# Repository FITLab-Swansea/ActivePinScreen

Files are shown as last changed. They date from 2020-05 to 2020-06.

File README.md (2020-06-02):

# Active PinScreen
Active PinScreen is a new tactile feedback technique, that applies localised stimuli on multiple fingers with fine spatial and temporal resolution. It uses an array of solenoid-actuated magnetic pins with millimetre scale form-factor which could be deployed for back-of-device handheld use without instrumenting the user.

See the [toolkit website](https://breaking-the-glass.com/toolkit.html) and [research project website](https://breaking-the-glass.com) for more details and related work.
## Getting Start
To build your own Active PinScreen, the following instructions will get you a copy of the project up and running on your local machine for development and testing purposes. See deployment for notes on how to deploy the project on a live Active PinScreen.

As well as presenting a detailed description of the prototype, we provide the potential design configurations and the applications of Active PinScreen.

* [Prototype](Prototype/)
* [Circuit layouts & microcontroller code](Electronics%20and%20microcontroller%20code/)
* Examples of Android App source code see: [TacCar](EndlessRunner), [TacPacMan](TacPacMan) and [TacPinao](TapPinao).

## License

This project is licensed under the MIT License - see the [LICENSE](LICENSE) file for details.

The Active PinScreen's prototype designs, circuit layouts, microcontroller code and accompanying Android app source code are all released.

## Acknowledgments

* FitLab
* Swansea University
* ...

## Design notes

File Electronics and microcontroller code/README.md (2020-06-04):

# Active PinScreen Electronics and Microcontroller
Active PinScreen is controlled using a custom-made circuit board, which runs a 8X8 pin array and a Bluetooth module, and provides handles battery charging.

## Getting Start
This repository provides [circuit diagrams](Gerber%20files/), a [bill of materials](Coil%20array%20BOM.xls) and [parts coordinates list](partslist_coil.xls), a [list of commands](Coils-protocol.pdf), and [general hardware documentation](pintoy_paper.pdf).

You will also need the following (or similar), in addition to the circuit board:

* A Bluetooth HC-05 module
* Two lithium-polymer battery
* Optional: Two DPST switchers ([examples](https://onecall.farnell.com/c-k-components/l201011ss03q/slide-switch-dpst-4a-125v-panel/dp/2931771))
* Optional: Two extra 100 kOhm resistors for the battery monitor feature

The prototype’s solenoids are in practice activated one-by-one, their fast response time, combined with pulse-width modulation means that this is imperceptible to the user. Users are able to feel multiple pins simultaneously.

Therefore, the Active PinScreen, can be programed to form a particular pattern based on the "frame" and "sequence" defined in [Coils array communication protocol](Coils-protocol.pdf).
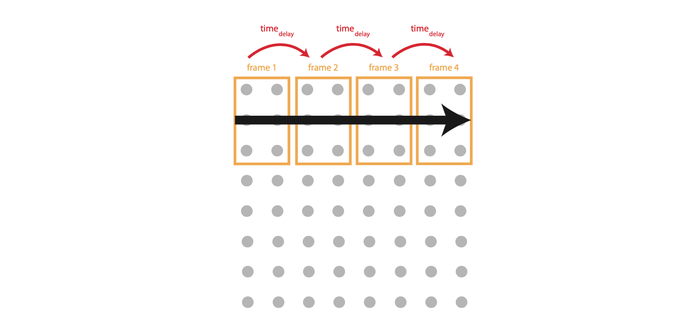
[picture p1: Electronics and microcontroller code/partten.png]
An example of the sequence of left to right directional pattern is shown in the following figure. The stimulation consists of four frames (each consisting of 2 × 3 (W × L) pins). 

## Pattern Programming
In order to create different types of stimuli, we needed to generate a sequence of activated pins in the following way:
* Define a block pattern which is known as a frame. Each pin in a frame will be activated simultaneously (or seemingly so from the user’s perspective, but actually by careful design of the pulse widths and duty cycles of each pin as described below);
* Define the actuation time of each frame, known as time actuation, which is the time each frame continues to be active for;
* Define the frame to frame delay, known as time delay, which refers to the pause between each frame being actuated;
* Create directional pattern by ‘drawing’ each frame on pin array;
* Using the frame and parameters time actuation and time delay, run the stimuli in sequence (i.e., frame by frame)
until the pattern is complete.

## License

This project is licensed under the MIT License - see the [LICENSE](LICENSE) file for details.

The Active PinScreen's prototype designs are released.

## Acknowledgments

* FitLab
* Swansea University
* ...

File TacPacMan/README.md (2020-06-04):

# TacPacMan
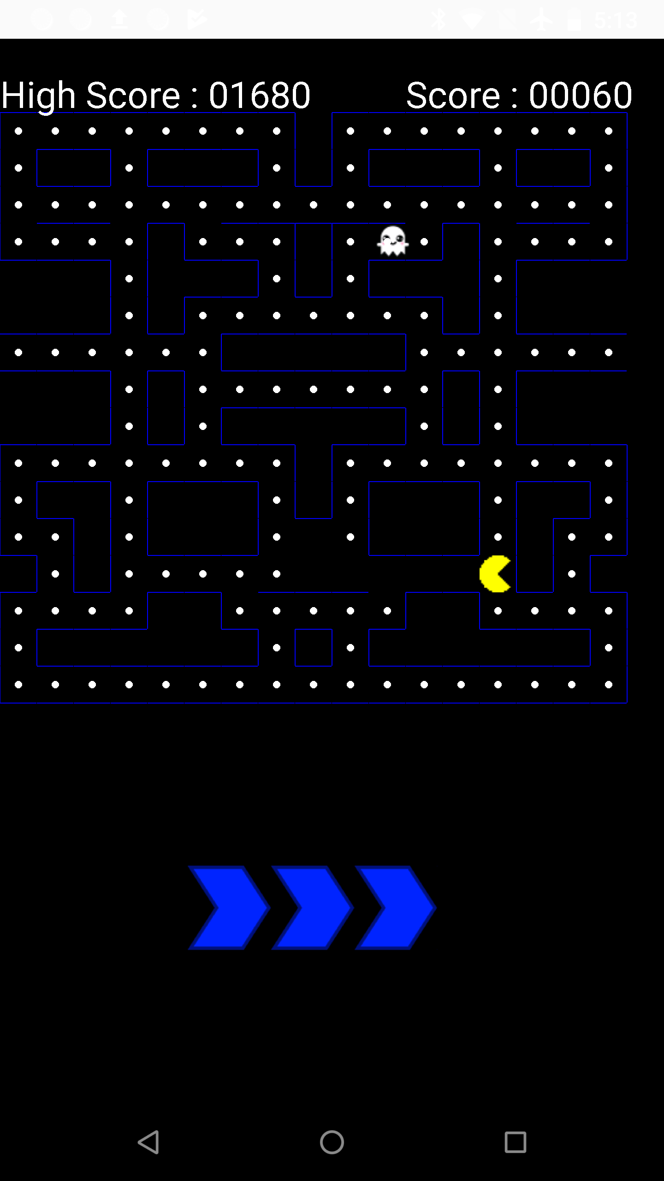
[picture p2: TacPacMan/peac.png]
f1
TacPacMan is an Android game which work with Active PinScreen. The left/right and up/down swipes on the front screen of the Pacman game are reflected within and inter-finger stimuli at the back of the device.

## License

This project is licensed under the MIT License - see the [LICENSE](LICENSE) file for details.

The Active PinScreen's prototype designs, circuit layouts, microcontroller code and accompanying Android app source code are all released.

## Acknowledgments

* FitLab
* Swansea University
* ...

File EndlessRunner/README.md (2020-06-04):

# Endless Runner
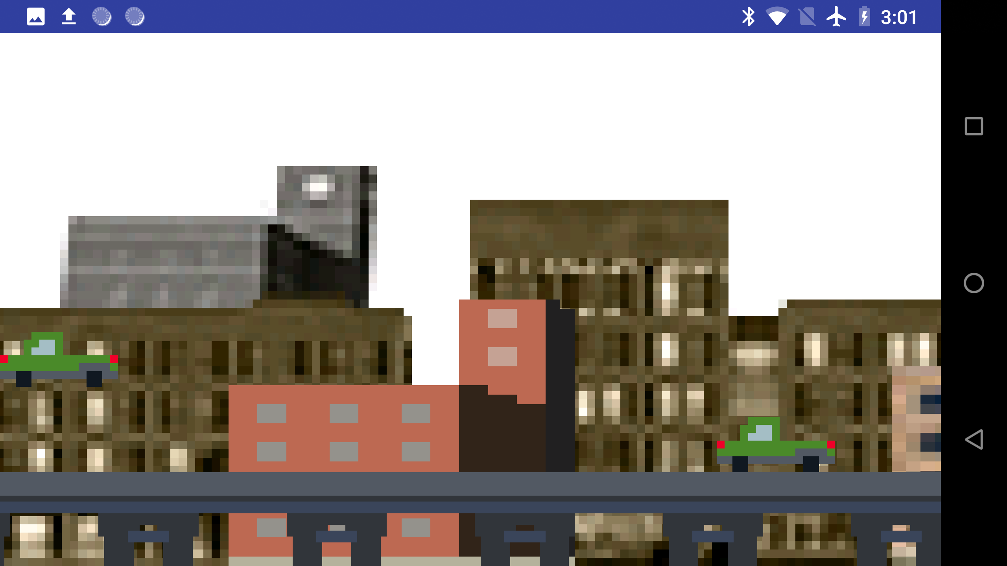
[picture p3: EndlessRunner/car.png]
f1
Endless Runner is an Android game which work with Active PinScreen. The "[car](car.png)" of the game can jump to avoid crush on "[the other car](car.png)" by tapping on the front screen. The inter-finger stimuli at the back of the device mimic this jump action.

## License

This project is licensed under the MIT License - see the [LICENSE](LICENSE) file for details.

The Active PinScreen's prototype designs, circuit layouts, microcontroller code and accompanying Android app source code are all released.

## Acknowledgments

* FitLab
* Swansea University
* ...

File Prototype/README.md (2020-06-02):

# Active PinScreen Prototype
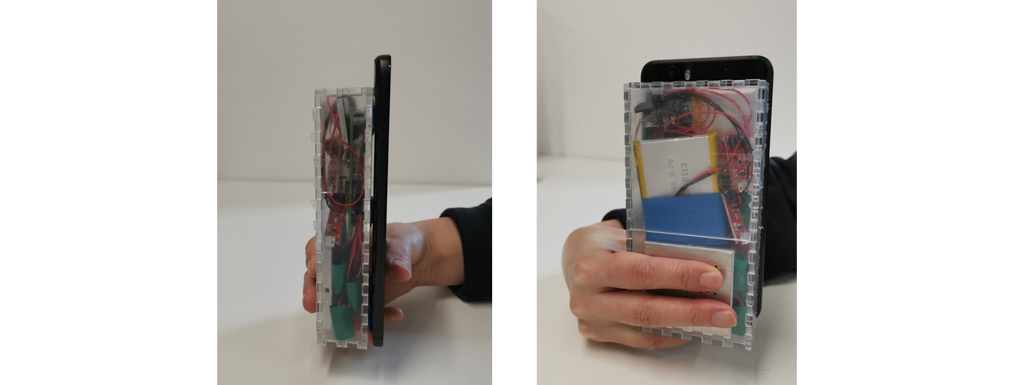
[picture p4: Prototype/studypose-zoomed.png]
The prototype can feasibly fit within the casing of a standard smart-phone -- see the following figure.

## Getting Start
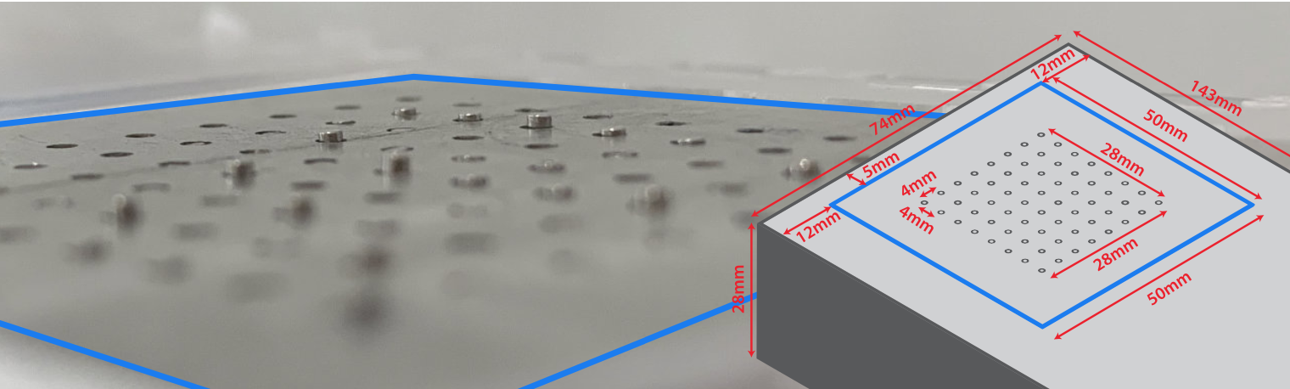
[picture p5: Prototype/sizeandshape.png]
array
The area which provided the tactile feedback are an 8×8 array of pins on the prototype are uniformly distributed over an area of 28 × 28 mm. The blue highlighted area affords the ability to fit comfortably on the back of a standard touchscreen device to provide high-precision feedback to multiple fingers at once. 

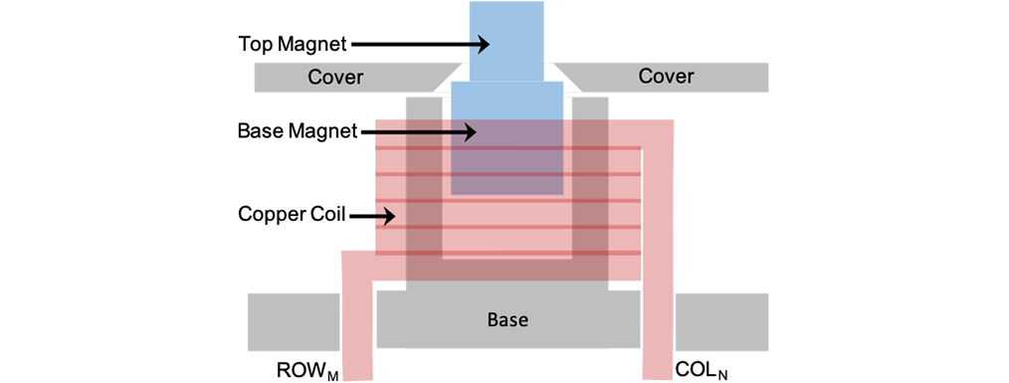
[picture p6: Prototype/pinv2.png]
arra
A close-up view of the device’s 1 mm diameter pins. A schematic of an individual in unit with its linear solenoid actuator and plunger is shown in the following figure.

* The plungers—the moving pins of the Active PinScreen—are magnetic, and consist of two permanent neodymium magnets.
* The base magnets have a diameter and thickness of 1.5 mm, and slide through the air-core of the solenoid, trapped inside by unit’s top-cover. The top magnets are adhered to the base magnets, and have a diameter and thickness of 1 mm. When activated, these magnets emerge through the unit’s cover and produce the tactile stimulation effect on the user’s fingers.
* The base is made of 8 mm acrylic, and the top cover of the device is a 2 mm aluminium plate.
* The inner tube and the air core for the solenoid in the base plate, and the 1.35 mm holes in the top plate are precisely cut using a CNC machine. A 32 gauge copper wire is wound approximately 25 turns to make each solenoid in the array. The coil ends of each solenoid are connected in rows and columns with a diode and two transistors (N- and P-type MOSFET) used to switch an active-matrix configuration.
* The solenoids are actuated one-at-a-time using a Microchip 18F47J53 8-bit microcontroller, with active matrix layouts transferred via Bluetooth from a smartphone.

## License

This project is licensed under the MIT License - see the [LICENSE](LICENSE) file for details.

The Active PinScreen's prototype designs are released.

## Acknowledgments

* FitLab
* Swansea University
* ...

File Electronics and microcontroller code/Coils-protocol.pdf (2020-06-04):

## Coils array communications protocol

Defining Frames

Commands are sent as $Axxx where A is the command letter listed below, and xxx is a three-digit numerical value for the parameter. All commands are always 5 characters long i.e. starting with a $, and ending with xxx, even if the command doesn’t require a numerical component/parameter.
All communication is carried out at 9600 BAUD (this will be increased to either 19200, 38400, or even possible 115200 BAUD when I get time)
$Lxxx
List stored frame data
$Cxxx
Clear stored frame data
$Fxxx
Start frame definition for frame xxx $Dxxx
Set coil-coil delay, x 1 ms
$Pxxx
Set coil “on-time”, x 100 us
$Nxxx
Set number of coils in sequence to xxx (N)
$Xxxx
Start coils definition from sequence value xxx, i.e. from xxx = 0 to xxx = N-1, where maximum number of coils in sequence is N-1
Note that X is set to zero when you start a frame definition
$Yxxx
Define coil X as xxx
Note that X will increment with each definition of Y so you don’t really need to use $X000 at all $Gxxx
Once the system is running, this will run Sequence xxx, where sequences start with 000.

Example
$F000
$N005
$D030
$P007
$Y003
$Y007
$Y030
$Y045
$Y063
$T000 (frame definition terminated as all details have been sent) $F001
$N003
$D025
$P006
$Y030
$Y045
$Y027
$T000

$L000 will list the 2 frames and their parameters/coil data $C000 will clear all frame definitions

Defining Sequences of Frames

A Sequence is a list of Frames, with each frame having a Repeat number i.e. how many times that frame should be “displayed” before moving onto the next frame in the sequence.
$Sxxx
Define a sequence. Note that when you define a sequence, it is simply added to the list of sequences (currently, you cannot delete sequences, only add another…)
Each sequence must have the number of frames for that sequence defined with
$nxxx
Where xxx is how many sets (frames with repeats) are included
$fxxx
xxx the frame number
$rxxx
Xxx is the number of times to repeat the above defined frame

To define a sequence, complete the following instructions:

$Saaa
$n004
$f000 first frame
$r005 repeat frame 000 5 times $f001
$r010
$f003
$r007
$f002
$r010
$Taaa Terminate the sequence definition as we’ve added 4 frame “sets” to the sequence The above will be stored as “Sequence 0”
$Saaa
$n002
$f015
$r010
$f018
$r020
$Taaa
The above will be stored as “Sequence 1”

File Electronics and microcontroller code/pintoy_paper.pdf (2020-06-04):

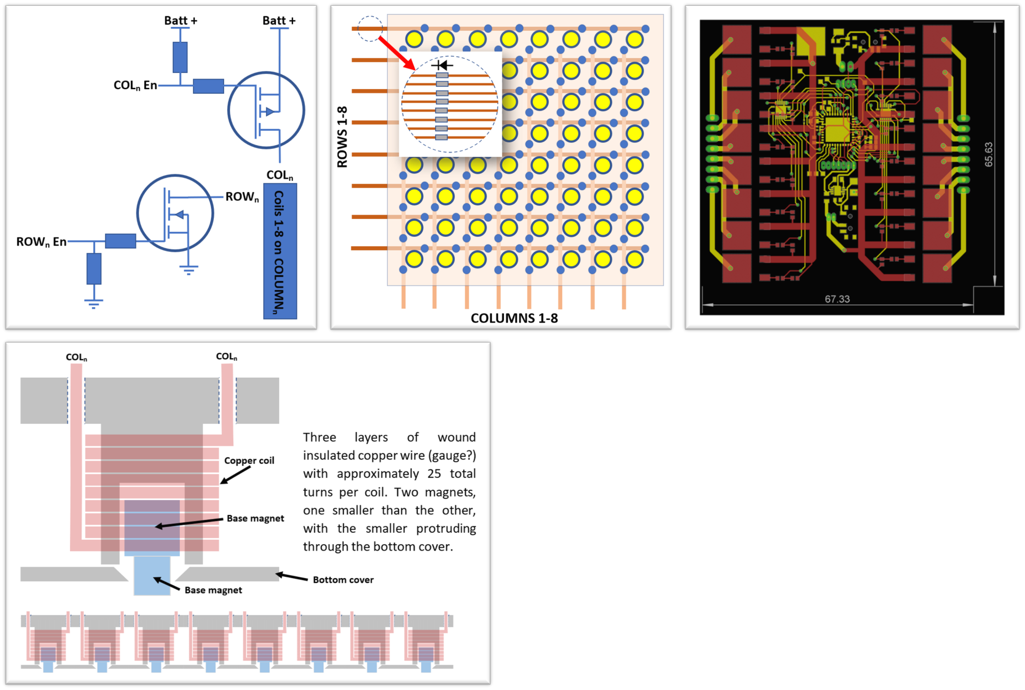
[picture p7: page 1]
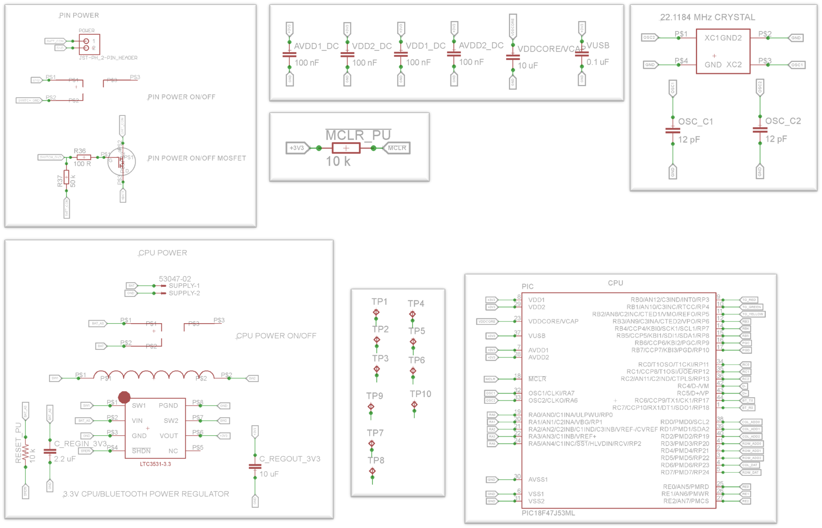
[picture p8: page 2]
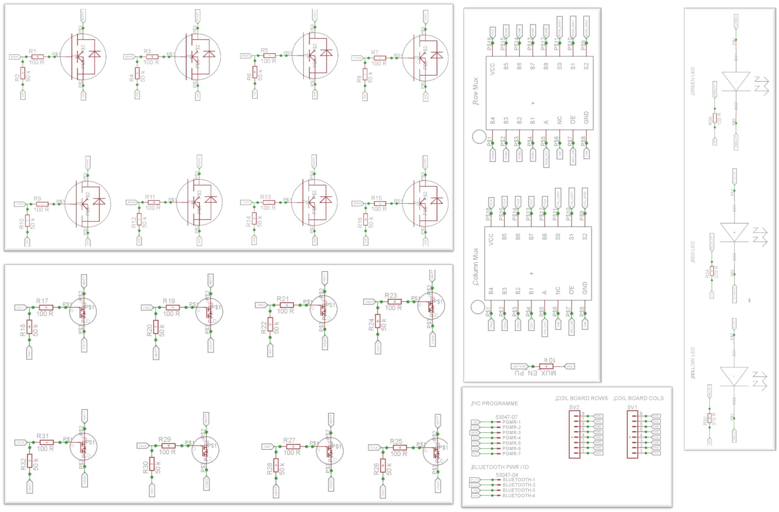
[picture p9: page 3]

This system comprises of several units

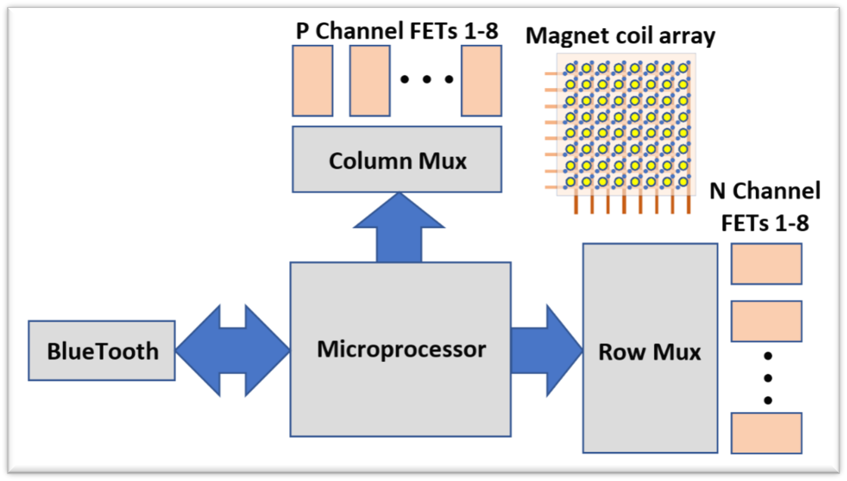
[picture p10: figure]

- Bluetooth module | Communication to / from a mobile phone or tablet
- CPU | To coordinate communications with mobile phone or tablet, and to store and control the flow of signals to the 8x8 magnet
| array
- Column/Row Mux | These units take a 3-bit binary address each to address 1 of 8 columns or rows, such that only a single coil is energised at
| any one time
- Magnet coil array | 8 x 8 coils, with the “end 1” of each coil in a column connected to a P channel MOSFET (per column), but with each coil “end
| 2” having its own individual diode at the “row” output, prior to the N channel MOSFET, present to ensure no current can
| slow back up a secondary coil on the same row

The processor selected for this project is MicroChip’s PIC47J53, an 8-bit microcontroller, comprising of 64 kByte of FLASH memory, primarily used for program storage, and 3.8 kByte of RAM. This device is driven by a 22.1184 MHz crystal, chosen to allow high serial communication BAUD rates, configured for 115,200 BAUD, permissible via the attached HC-05 serial Bluetooth module. Two batteries are used; one of large capacity used to deliver current through the coils, and the other for the CPU/control electronics. Two batteries are used as, if the larger battery was used to both dump current through coils, and for the control circuitry, there is the chance that its voltage may drop below that required for the voltage regulator and cause a reset. Dumping current through the coils, one at a time, is achieved by switching on 2 transistors (MOSFETS), effectively “shorting” the battery to itself for the briefest of moments.
At power on, the system clears its internal pattern buffers ready to receive data from the user. Several commands are used to assign parameters that dictate which coils will be energised in a frame, and in which order, how long current is allowed to flow through them, one at a time, the pause duration after one coil is switched off, before the next is switched on, and how many times an individual coil is toggled on/off, before progressing onto the next. A sequence can then be defined, comprising of one or more frames, repeated n times. These frames and sequences are uploaded in a matter of seconds from the user’s mobile phone or tablet. The user then instructs the device to execute a sequence of frames.

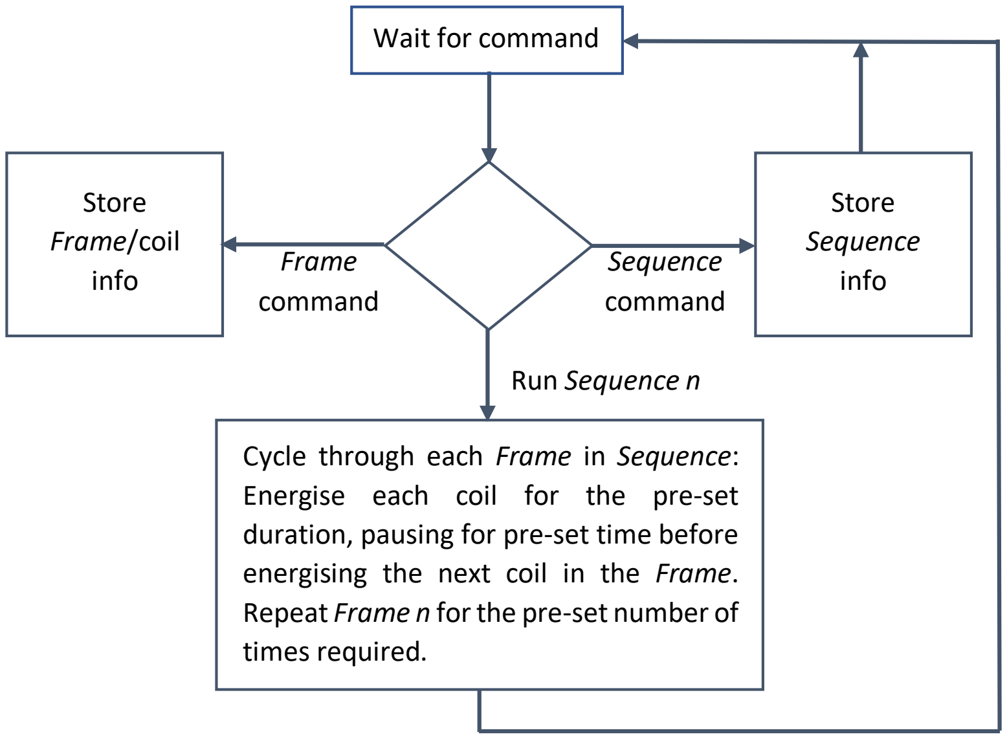
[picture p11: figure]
Wait for command; Frame command; Store Frame/coil info; Store Sequence info Sequence command; Run Sequence n; Cycle through each Frame in Sequence: Energise each coil for the pre-set; energising the next coil in the Frame.; times required.

duration, pausing for pre-set time before

Repeat Frame n for the pre-set number of

The current flowing through a coil is the order of several amperes(battery capacity / charge dependent), for the briefest of moments, typically sub-millisecond. This duration is more than enough to “kick” the two magnets residing inside each coil. Also, as each coil is on for less that one millisecond, several other coils in the 8x8 array can then be energised, with the selected coils energising in a cyclic fashion at up the 40 Hz, or possibly more. This high level of control on how much current flows through a coil (timewise), and how often this occurs per coil, allows for a varying degree of sense of “strength” when the magnets are touched by the hand or fingers. With the microprocessor running at 22 MHz, this allows for a fair degree of precision regarding the timing of the coils. The pause time between energising coils is defined “per millisecond”, while the coil “on-time” is “per 100 microseconds”. No higher resolution was deemed necessary but is certainly possible should it be required.
Estimated field strength per coil can be estimated with a well-known equation:

B = μnI
Where
μ is the permeability; for neodymium magnets, this is approximately 1.32x10⁻⁶ H/m
n is the number of turns in the coil per metre, or the “turns density” N/L; for this device, approximately 24 turns per 4 mm I is the current flowing in the coil, A

Therefore, the magnetic field strength is of the order of 24 mT

PIC18F47J53 (PICBASIC3)
Include "modedefs.bas"
#CONFIG

CONFIG XINST = OFF
CONFIG WDTEN = ON
CONFIG WDTPS = 512
CONFIG ADCSEL = BIT12
CONFIG RTCOSC = T1OSCREF
CONFIG OSC = HSPLL
CONFIG CLKOEC = OFF
CONFIG CFGPLLEN = OFF
CONFIG CP0 = ON
CONFIG IESO = ON
CONFIG SOSCSEL = LOW
CONFIG CPUDIV = OSC1
#ENDCONFIG

DEFINE OSC 20 ' 20MHz oscillator (22.1184MHz)
DEFINE HSER_RCSTA 90h ' Enable serial port & continuous receive DEFINE HSER_TXSTA 20h ' Enable transmit, BRGH = 1
DEFINE HSER_CLROERR 1 ' Clear overflow automatically
DEFINE HSER_SPBRG 11 ' 115200 Baud @ SPBRGH = 0
BAUDCON.3 = 1 | ' Enable 16 bit baudrate generator
command | var byte[4]
frame_pointer | var word[100]
frame_sequence_repeats | var byte[500]
frame_data | var byte[1500]
frame_sequence_data | var byte[1000]
frame_sequence_ptr | var word[100]
frame_sequence_f_f_pause | var byte[100]
command_ptr | var word
search_bearing | var bit
command_value | var byte

command_go | var byte
define_frame_point_x | var byte
number_of_coils_in_frame | var byte
frame_started | var byte
coil_on_time | var word
coil_coil_delay | var byte
data_mode | var byte
cnt | var word
cnt2 | var byte
cnt3 | var byte
max_frame_defined | var byte
frame_frame_delay | var byte
ser_spd | var byte
frame_number | var byte
frame_sequence_num | var byte
frame_seq_started | var byte
max_sequence_defined | var byte
frame_sequence_frame_counter var byte
repeat_frame | var byte
coil_num | var byte
verbose | var byte
trisa.3 | = 0 ' !mux_en
trisd | = 0 ' set all portd = output
mux_en | var lata.3
col_dat | var latd.6
row_dat | var latd.7
col_add0 | var latd.0
col_add1 | var latd.1
col_add2 | var latd.2
row_add0 | var latd.3

row_add1 | var latd.4
row_add2 | var latd.5
data_mode | = 0
coil_coil_delay | = 0
coil_on_time | = 0
frame_started | = 0
number_of_coils_in_frame | = 1
define_frame_point_x | = 0
command_go | = 0
max_frame_defined | = 0
max_sequence_defined | = 0
frame_sequence_frame_counter = 0
frame_sequence_num | = 0
verbose | = 0
mux_en | = 1 | ' !mux_en = mux's disabled

low col_add0
low col_add1
low col_add2

low row_add0
low row_add1
low row_add2

high col_dat ' all columns off high row_dat ' all rows on

low mux_en

T2CON | = %00000000 ' Turn off timer2
INTCON.7 | = 0 | ' Disable interrupts.
PR2 | = 255 | ' PWM frequency.
T2CON | = %00000100 ' Timer2 ON + 1:1 prescale

Serial_in | var portc.7
green_led | var portb.1
red_led | var portb.0
yellow_led | var portb.2
key_press | var portb.7
Serial_out | var portc.6
intcon | = 0
intcon2 | = %11110101
intcon3 | = %00000000
trisb.3 | = 0
trisa.1 | = 0
trisa.2 | = 1
'trisa.3 | = 1
command_ptr | = 0
frame_number | = 0

main:

gosub clear_arrays

HSerout [$d,$a,"Coil array"]

high green_led

command_ptr = 0
pause 200

high green_led

low yellow_led
pause 100
low green_led

pause 50
pp:

HSerout [$d,$a,"Waiting for instruction",$d,$a]

command_go = 0

high green_led
gosub listen_for_commands
gosub execute_commands
low yellow_led
goto pp
end

listen_for_commands:

while command_go = 0
hserout [$d,$a,dec frame_number," > "]
hserin [wait("$"),str command\4]
hserout ["$",str command\4]

command_value = (command[1] - 48) * 100 + (command[2] - 48) * 10 + (command[3] - 48)
if command[0] = 100 then ' sequence array dump | d
for cnt = 0 to 50
hserout[$d,$a,"PTRs: ",dec cnt," ",dec frame_sequence_ptr[cnt]]
next cnt
for cnt = 0 to 50
hserout[$d,$a,"data: ",dec cnt," ",dec frame_sequence_data[cnt]] next cnt
for cnt = 0 to 50
hserout[$d,$a,"rpts: ",dec cnt," ",dec frame_sequence_repeats[cnt]] next cnt
endif
if command[0] = 76 then ' list stored data | L

HSerout [$d,$a,"List stored commands"]

for cnt = 0 to max_frame_defined
hserout[$d,$a,$a,"Frame #",dec cnt]
hserout[$d,$a,"Time-on ",dec frame_data[frame_pointer[cnt]+2]] hserout[$d,$a,"Coil-coil time ",dec frame_data[frame_pointer[cnt]+1]] hserout[$d,$a,"Number of coils in frame ",dec frame_data[frame_pointer[cnt]+0]] for cnt2 = 0 to (frame_data[frame_pointer[cnt]+0] - 1)
hserout[$d,$a,"Coil X:",dec cnt2," = ",dec frame_data[frame_pointer[cnt]+3 + cnt2]] next cnt2
hserout[$d,$a]
next cnt

for cnt = 0 to (max_sequence_defined - 1)
hserout[$d,$a,$a,"Sequence #",dec cnt]
hserout[$d,$a,"Number of frame sets in this sequence ",dec frame_sequence_repeats[frame_sequence_ptr[cnt] + 0]]
for cnt2 = 0 to (frame_sequence_repeats[frame_sequence_ptr[cnt] + 0] - 1)
hserout[$d,$a,"Frame set #",dec cnt2," = Frame #",dec frame_sequence_data[frame_sequence_ptr[cnt] + 1 + cnt2]," repeated #",dec frame_sequence_repeats[frame_sequence_ptr[cnt] + 1 + cnt2]," times"]
next cnt2
hserout[$d,$a]
next cnt
endif
if command[0] = 67 then ' clear stored data | C
HSerout [$d,$a,"Clear stored commands"]

max_frame_defined = 0
max_sequence_defined = 0
frame_started = 0

for cnt = 0 to 2999
frame_data[cnt] = 0
next cnt

for cnt = 0 to 99

frame_pointer[cnt] = 0
next cnt

for cnt = 0 to 499
frame_sequence_data[cnt] = 0 next cnt

for cnt = 0 to 499
frame_sequence_repeats[cnt] = 0 next cnt

for cnt = 0 to 29
frame_sequence_ptr[cnt] = 0
next cnt

endif

if command[0] = 77 then ' set data mode | M
if frame_started = 1 then
HSerout [$d,$a,"Data mode = ",dec data_mode]
else
HSerout [$d,$a,"Please start a frame definition with $Fxxx"] endif
endif
if command[0] = 68 then ' set coil - coil delay | D
if frame_started = 1 then
if verbose = 1 then HSerout [$d,$a,"Frame #",dec frame_number," coil-to-coil delay = ",dec command_value] coil_coil_delay = command_value
frame_data[frame_pointer[frame_number]+1] = coil_coil_delay
else
HSerout [$d,$a,"Please start a frame definition with $Fxxx"] endif
endif
if command[0] = 86 then ' set coil - coil delay | D

verbose = command_value

hserout [$d,$a, "Verbose mode = ",dec verbose]
endif
if command[0] = 80 then ' set coil on-time x100 us | p
if frame_started = 1 then
if verbose = 1 then HSerout [$d,$a,"Frame #",dec frame_number," on-time = ",dec command_value] coil_on_time = command_value
frame_data[frame_pointer[frame_number]+2] = coil_on_time
else
HSerout [$d,$a,"Please start a frame definition with $Fxxx"] endif
endif
if command[0] = 84 then ' terminate frame definition | T
if verbose = 1 then
if frame_started = 1 then
HSerout [$d,$a,"Frame #",dec frame_number," ended"] endif
endif
if verbose = 1 then
if frame_seq_started = 1 then
HSerout [$d,$a,"sequence ",dec (frame_sequence_num - 1)," ended"] endif
endif
frame_started = 0
frame_seq_started = 0

endif

if command[0] = 70 then ' Define frame number | F
if frame_started = 0 then
frame_number = command_value
define_frame_point_x = 0 if frame_number > max_frame_defined then max_frame_defined = frame_number

frame_started = 1
if verbose = 1 then HSerout [$d,$a,"Frame definition started #",dec command_value]

if frame_number == 0 then
frame_pointer[0] = 0
else
frame_pointer[frame_number] = frame_pointer[frame_number - 1] + frame_data[frame_pointer[frame_number - 1]] + 3 ' previous frame start + number of point + 3 vars: coils, delay and on-time
endif
else
HSerout [$d,$a,"Please end current frame definition"]
endif
endif

if command[0] = 78 then ' define number of coils in current frame N
if frame_started = 1 then
if verbose = 1 then HSerout [$d,$a,"Frame #",dec frame_number," number of coils = ",dec command_value] number_of_coils_in_frame = command_value
frame_data[frame_pointer[frame_number]] = number_of_coils_in_frame
else
HSerout [$d,$a,"Please start a frame definition with $Fxxx"]
endif
endif
if command[0] = 83 then ' start to define a frame sequence | S
if frame_started = 0 then
frame_sequence_num = frame_sequence_num + 1 frame_sequence_frame_counter = 0
frame_seq_started = 1
max_sequence_defined = max_sequence_defined + 1

if verbose = 1 then HSerout [$d,$a,"frame_sequence_num: ",dec frame_sequence_num]
if verbose = 1 then HSerout [$d,$a,"frame_sequence_ptr[frame_sequence_ptr[frame_sequence_num - 2]]: ",dec (frame_sequence_ptr[frame_sequence_ptr[frame_sequence_num - 2]])]

if verbose = 1 then HSerout [$d,$a,"frame_sequence_repeats[frame_sequence_ptr[frame_sequence_num - 2]]: ",dec (frame_sequence_repeats[frame_sequence_ptr[frame_sequence_num - 2]])]

if frame_sequence_num = 1 then
frame_sequence_ptr[frame_sequence_num - 1] = 0
else
frame_sequence_ptr[frame_sequence_num - 1] = frame_sequence_ptr[frame_sequence_num - 2] + frame_sequence_repeats[frame_sequence_ptr[frame_sequence_num - 2]] + 1
endif
if verbose = 1 then HSerout [$d,$a,"PTR (",dec (frame_sequence_num - 1),"): ",dec (frame_sequence_ptr[frame_sequence_num - 1])]
if verbose = 1 then HSerout [$d,$a,"Defining sequence ",dec (frame_sequence_num - 1),". Start sending data with $nxxx for number of frame sets in sequence, then $fxxx for frame number followed by $rxxx for repeats of that frame. $Txxx to terminate sequence once the sets have been defined"] else
HSerout [$d,$a,"Please start a frame definition with $Fxxx"]
endif
endif
if command[0] = 102 then ' define sequence frame | f
if frame_seq_started = 1 then
frame_sequence_data[frame_sequence_ptr[frame_sequence_num - 1] + 1 + frame_sequence_frame_counter] = command_value
if verbose = 1 then HSerout [$d,$a,"Sequence #",dec (frame_sequence_num - 1)," frame-in-sequence #",dec frame_sequence_frame_counter," frame #",dec command_value]
else
HSerout [$d,$a,"Please start frame sequence with $Sxxx"]
endif
endif

if command[0] = 110 then ' define number of sets in this sequence n
if frame_seq_started = 1 then
frame_sequence_repeats[frame_sequence_ptr[frame_sequence_num - 1] + 0] = command_value
if verbose = 1 then HSerout [$d,$a,"Sequence #",dec (frame_sequence_num - 1)," has #",dec command_value," frame sets"] else
HSerout [$d,$a,"Please start frame sequence with $Sxxx"]
endif
endif if command[0] = 112 then ' define frame-frame pause during repeats p
if frame_seq_started = 1 then
frame_sequence_f_f_pause[frame_sequence_ptr[frame_sequence_num - 1] + 0] = command_value
if verbose = 1 then HSerout [$d,$a,"Sequence #",dec (frame_sequence_num - 1)," frame-frame delay ",dec command_value," ms"] else
HSerout [$d,$a,"Please start frame sequence with $Sxxx"]
endif
endif
if command[0] = 114 then ' define sequence frame repeats | r
if frame_seq_started = 1 then
if frame_sequence_frame_counter < frame_sequence_repeats[frame_sequence_ptr[frame_sequence_num - 1] + 0] then frame_sequence_repeats[frame_sequence_ptr[frame_sequence_num - 1] + 1 + frame_sequence_frame_counter] = command_value
if verbose = 1 then HSerout [$d,$a,"Sequence #",dec (frame_sequence_num - 1)," set #",dec frame_sequence_frame_counter," frame #",dec frame_sequence_data[frame_sequence_ptr[frame_sequence_num - 1] + 1 + frame_sequence_frame_counter]," repeats #",dec frame_sequence_repeats[frame_sequence_ptr[frame_sequence_num - 1] + 1 + frame_sequence_frame_counter]] frame_sequence_frame_counter = frame_sequence_frame_counter + 1
else
if verbose = 1 then HSerout [$d,$a,"Maximum number of frame sets define; please terminate with $Txxx"] endif
else
HSerout [$d,$a,"Please start frame sequence with $Sxxx"]
endif
endif

if command[0] = 88 then ' about to define coil in sequece no. X X if frame_started = 1 then
if command_value < number_of_coils_in_frame then define_frame_point_x = command_value
HSerout [$d,$a,"Start defining coils from ",dec command_value]
else
HSerout [$d,$a,"Please keep coil definitions within N-1: ",dec number_of_coils_in_frame] endif
else
HSerout [$d,$a,"Please start a frame definition with $Fxxx"]
endif

endif

if command[0] = 69 then ' sequence through all of the coils 1 to 64 for cnt = 0 to 63 step 1

coil_num = cnt

for cnt2 = 0 to 25

gosub energise
gosub energise

next cnt2

next cnt
endif
if command[0] = 89 then ' point X (max N-1) = Y | Y
if frame_started = 1 then
if define_frame_point_x < number_of_coils_in_frame then
if verbose = 1 then HSerout [$d,$a,"Frame #",dec frame_number," seq no. ",dec define_frame_point_x," coil = ",dec command_value," (0-63)"] frame_data[frame_pointer[frame_number]+3 + define_frame_point_x] = command_value
define_frame_point_x = define_frame_point_x + 1
else
HSerout [$d,$a,"Coil sequence out of range. Max coils = ",dec number_of_coils_in_frame] endif
else
HSerout [$d,$a,"Please start a frame definition with $Fxxx"]
endif
endif
if command[0] = 71 then ' go - execute all stored commands | G
HSerout [$d,$a,"Execute sequence #",dec command_value]
gosub execute_commands
endif

wend

return

execute_commands:

for cnt = 0 to (frame_sequence_repeats[frame_sequence_ptr[command_value] + 0] - 1) ' run through all frames in this sequence

coil_coil_delay | = frame_data[frame_pointer[frame_sequence_data[frame_sequence_ptr[command_value] + 1 + cnt]] + 1]
coil_on_time | = frame_data[frame_pointer[frame_sequence_data[frame_sequence_ptr[command_value] + 1 + cnt]] + 2]
number_of_coils_in_frame | = frame_data[frame_pointer[frame_sequence_data[frame_sequence_ptr[command_value] + 1 + cnt]] + 0]
repeat_frame | = frame_sequence_repeats[frame_sequence_ptr[command_value] + 1 + cnt]
frame_frame_delay | = frame_sequence_f_f_pause[frame_sequence_ptr[command_value] + 0]

if verbose = 1 then HSerout [$d,$a,$d,$a, "Frame #",dec frame_sequence_data[frame_sequence_ptr[command_value] + 1 + cnt]]
if verbose = 1 then HSerout [$d,$a, | "Coil_coil_delay #",dec coil_coil_delay]
if verbose = 1 then HSerout [$d,$a, | "Coil_on_time #",dec coil_on_time]
if verbose = 1 then HSerout [$d,$a, | "Number_of_coils_in_frame #",dec number_of_coils_in_frame]
if verbose = 1 then HSerout [$d,$a, | "Repeat frame #",dec repeat_frame]

if verbose = 1 then
for cnt2 = 0 to (frame_data[frame_pointer[frame_sequence_data[frame_sequence_ptr[command_value] + 1 + cnt]] + 0] - 1)

HSerout [$d,$a, "Coil #",dec frame_data[frame_pointer[frame_sequence_data[frame_sequence_ptr[command_value] + 1 + cnt]] + 3 + cnt2]]

next cnt2
endif

if verbose = 1 then HSerout [$d,$a,$d,$a, "Begin frame #",dec frame_sequence_data[frame_sequence_ptr[command_value] + 1 + cnt]," and repeat #",dec repeat_frame," times"]

coil_on_time = 100 * coil_on_time

for cnt3 = 0 to (repeat_frame - 1)

for cnt2 = 0 to (frame_data[frame_pointer[frame_sequence_data[frame_sequence_ptr[command_value] + 1 + cnt]] + 0] - 1) ' slide through each coil in this frame (cnt)

COIL_NUM = frame_data[frame_pointer[frame_sequence_data[frame_sequence_ptr[command_value] + 1 + cnt]] + 3 + cnt2]

GOSUB energise

pause coil_coil_delay ' ms

next cnt2

HSerout [$d,$a, "Pause frame-frame"]

pause frame_frame_delay

next cnt3

if verbose = 1 then HSerout [$d,$a,$d,$a, "End frame #",dec frame_sequence_data[frame_sequence_ptr[command_value] + 1 + cnt]]

next cnt

HSerout [$d,$a, "End of sequence"]

return

energise:

col_add0 = coil_num & $1
col_add1 = (coil_num & $2) >> 1 col_add2 = (coil_num & $4) >> 2 row_add0 = (coil_num & $8) >> 3 row_add1 = (coil_num & $10) >> 4 row_add2 = (coil_num & $20) >> 5

high green_led

low col_dat ' enable coil
pauseus coil_on_time
high col_dat ' disable coil

low green_led

return

clear_arrays:

for cnt = 0 to 999
frame_data[cnt] = 0
next cnt

for cnt = 0 to 99
frame_pointer[cnt] = 0
next cnt

for cnt = 0 to 499
frame_sequence_data[cnt] = 0 next cnt

for cnt = 0 to 499
frame_sequence_repeats[cnt] = 0 next cnt

for cnt = 0 to 299
frame_sequence_ptr[cnt] = 0 next cnt

return

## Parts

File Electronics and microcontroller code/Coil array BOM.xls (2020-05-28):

Quantity | Designator | Description | Manufacturer | Manufacturer Part Number | Supplier 1 | Supplier Part Number 1 | Notes
2 | OSC_C1, OSC_C2 | 12 pF, 25 V, +/- 5%, C0G / NP0, MLCC, 0201 | Kemet | C0201C120J3GACTU | Farnell | 2821255
4 | AVDD1_DC, AVDD2_DC, VDD1_DC, VDD2_DC | 100 nF, 6.3 V, +/- 10%, X5R MLCC, 0201 | Kemet | C0201C104K9PACTU | Farnell | 1907036
1 | VUSB | 100 nF, 10 V +/- 10%, X7R, MLCC, 0402 | Multicomp | MC0402B104K100CT | Farnell | 2627343
1 | C_REGIN_3V3 | 2.2 uF X7R 25V 1206 Capacitor, 1206 | Multicomp | MC1206B225K250CT | Farnell | 2310423
1 | C_REGOUT_3V3 | 10 uF 6.3V X5R 0805 Capacitor, 0805 | Multicomp | MC0805X106K6R3CT | Farnell | 2320852
1 | VDDCORE/VCAP | 10 uF, 6.3 V, +/- 20%, X5R MLCC, 0402 | Murata | GRM155R60J106ME44D | Farnell | 2218854
17 | R1, R3, R5, R7, R9, R11, R13, R15, R17, R19, R21, R23, R25, R27, R29, R31, R36 | 100 R, 50 V, Thick film, 63 mW, 0402 | Panasonic | ERJ2RKF1000X | Farnell | 2302528
1 | R35 | 120 R, 50 V, Thick film, 63 mW, 0402 | Vishay | CRCW0402120RFKED | Farnell | 2140682
2 | R33, R34 | 270 R, 50 V, Thick film, 100 mW, 0402 | Panasonic | ERJ2GEJ274X | Farnell | 2324291
1 | RESET_PU | 10 k, 50 V, Thick film, 63 mW, 0402 | Vishay | CRCW040210K0FKED | Farnell | 1469669
2 | !MCLR_PU, MUX_EN_PU | 10 k, 25 V, Thick film 50 mW, 0201 | Multicomp | MCRE000164 | Farnell | 1711641
17 | R2, R4, R6, R8, R10, R12, R14, R16, R18, R20, R22, R24, R26, R28, R30, R32, R37 | 51 k, 50 V Thick film 62.5 mW, 0402 | Multicomp | MCWR04X5102FTL | Farnell | 2447195
1 | 221184XTAL | 22.1184 MHz Xtal, 2.5 x 2.0 mm | Quantek | QC2522.1184F12B12M | Farnell | 2508660
2 | ROW_MUX, COL_MUX | 8 channel multiplexer, 16-VQFN | TI | SN74CBTLV3251RGYR | Digikey | 296-15105-1-ND
1 | PIC | Microcontroller | Microchip | PIC18F47J53-I/ML | Digikey | PIC18F47J53-I/ML-ND
1 | U$1 | 3.3 V Buck/Boost regulator | Linear-Technology | LTC3531EDD-3.3 | Digkey | LTC3531EDD-3.3#PBF-ND
1 | U$2 | 10 uH 500 mA Inductor, 0805 | TDK | MLZ2012N100LT | Farnell | 2493070
1 | U$3 | Red LED, 0.8 x 1.1 mm | Panasonic Elec Cmpts | LNJ237W82RA | Farnell | 1908052
1 | U$4 | Green LED, 0.8 x 1.1 mm | Panasonic Elec Cmpts | LNJ326W83RA | Farnell | 1699415
1 | U$5 | Yellow LED, 0.8 x 1.1 mm | Panasonic Elec Cmpts | LNJ826W86RA | Farnell | 1908049
9 | MF_C1, MF_C2, MF_C3, MF_C4, MF_C5, MF_C6, MF_C7, MF_C8, MF_C9 | P channel MOSFET, TO252-3 | Infineon | IPD90P03P4L04ATMA1 | Farnell | 2432731
8 | MF_R1, MF_R2, MF_R3, MF_R4, MF_R5, MF_R6, MF_R7, MF_R8 | N Channel MOSFET, TO252-3 | Infineon | IPD031N03LGATMA1 | Farnell | 1775565
2 | U$6, U$7 | Slide switch | Copal | CUS-12B | Digikey | 563-1102-1-ND
1 | SUPPLY | Molex 2-pin top connector | Molex | 53047-0210 | Farnell | 9733051
1 | BLUETOOTH | Molex 4-pin top connector | Molex | 53047-0410 | Farnell | 9733060
1 | PGMR | Molex 7-pin top connector | Molex | 53047-0710 | Farnell | 9732870
1 | POWER | JST 2-pin top connector | JST | B2B-PH-K-S(LF)(SN) | Farnell | 9491856
2 | SV1, SV2 | Board-To-Board Connector, Right Angle, 2.54 mm, 8 Contacts, Header, MC34 Series, Through Hole | Multicomp | MC34753 | Farnell | 1593431
Compulsory columns highlighted in yellow

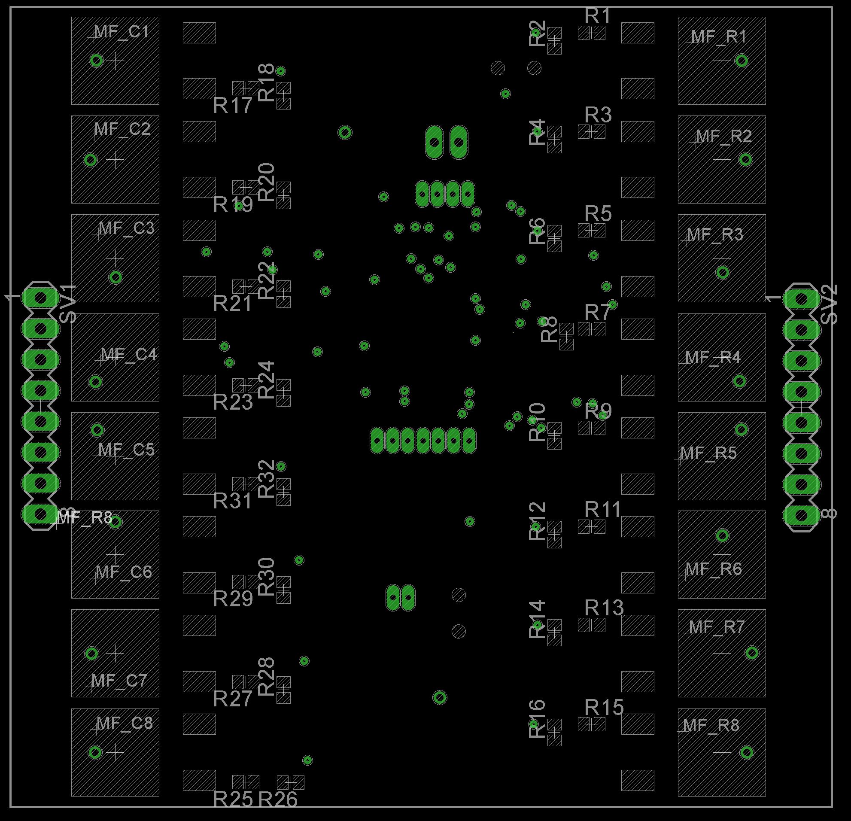
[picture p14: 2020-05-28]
Electronics and microcontroller code/top side components.JPG

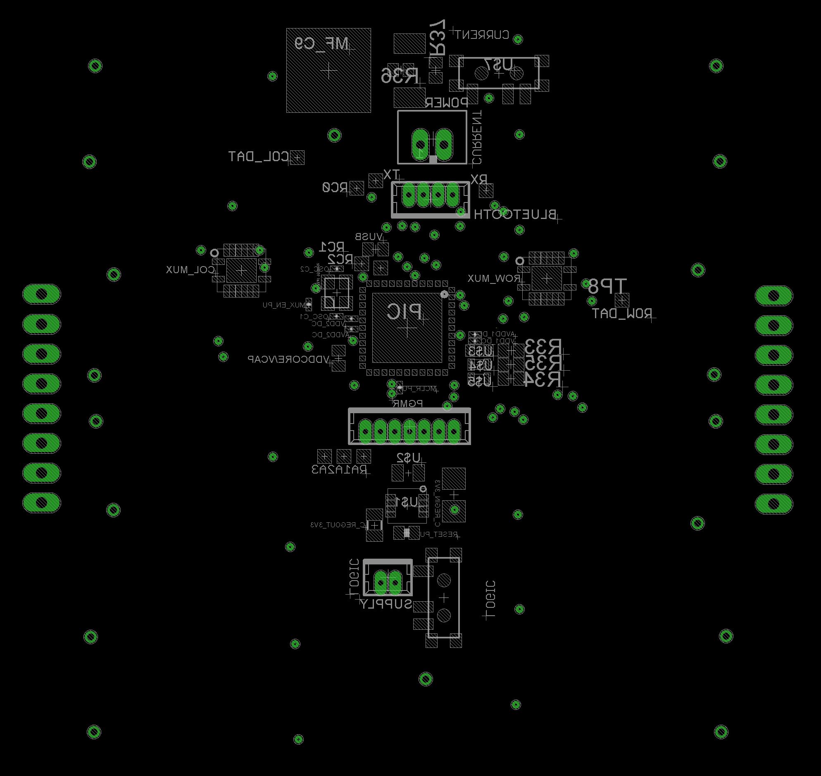
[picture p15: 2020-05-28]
Electronics and microcontroller code/bottom side components.JPG

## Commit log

2020-05-21 Add a running car game app，which user can feel the tactile feedback when the car jumping.
2020-05-21 Add a PacMan game app，which user can feel the four direction tactile feedbacks.
2020-05-28 Add the code for the electronics and the microcontroller of the Active PinScreen.
    [Coil array BOM.xls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]
2020-05-28 readme update insert the return
2020-06-02 Add the Prototype
2020-06-02 update prototype figure
2020-06-02 resize the prototype figure
